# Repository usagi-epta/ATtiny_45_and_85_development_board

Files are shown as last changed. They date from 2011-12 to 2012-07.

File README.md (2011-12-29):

ATtiny 45 and 85 Development Board
==================================
Copyright 2011 Design Tech Industries (DTI)

DTI email: <jameskun89@rocketmail.com>

The **ATtiny 45 and 85 Development Board** is a development board for the ATtiny 45 and 85 microcontroller.

Features:

 * All µC pins broken out
 * Power LED
 * Reset switch
 * ISP headers 
 * Open Source; OSHW compliant
 * Design files freely available

In this repository you will find the gerber files for BatchPCB (http://batchpcb.com) and DorkbotPDX (http://dorkbotpdx.org/wiki/pcb_order),
along with project (.pro), board (.brd) and schematic (.sch) files for the board in the 'EAGLE and 'KiCad' folders.

You can also find this design on BatchPCB ready to add to your cart: http://batchpcb.com/index.php/Products/73630

**This board will be under continual change and versions may not work the way they are supposed to. You have been warned**

INSTALLATION
------------
**EAGLE**
The design is saved as an EAGLE project. EAGLE PCB design software is available from www.cadsoftusa.com 
free for non-commercial use and can be installed on Windows and Mac, with Linux support through WINE. 
To use this project download it and place the directory containing these files into the "eagle" directory 
on your computer. Then open EAGLE and navigate to Projects -> eagle -> ATtiny_45_and_85_development_board.

**KiCad**
KiCad EDA Suite is an Open Source alternative to EAGLE. It is available on Windows and Linux and can be installed 
on Mac. It is available from http://kicad.sourceforge.net and works in a similar way to EAGLE. You will find project 
files for KiCad in the aptly named folder in this repository. To use this project download it and place the directory 
containing these files into a folder of your choice. Then open KiCad and navigate to File -> Open -> 
'FOLDER_OF_YOUR_CHOICE' -> ATtiny_45_and_85_development_board.pro

BILL OF MATERIALS
-----------------

 * 1 x ATtiny 45/85 µC (http://littlebirdelectronics.com/products/avr-8-pin-20mhz-8k-4ad-attiny85)
 * 1 x 8-pin DIP socket (http://littlebirdelectronics.com/products/dip-sockets-solder-tail-8pin)
 * 2 x Female Header - 1x4-pin, Straight (http://littlebirdelectronics.com/products/0100-254-mm-female-header-1x4-pin-straight)
 * 1 x Break Away Header - Right Angle (http://littlebirdelectronics.com/products/break-away-headers-right-angle)
 * 1 x 5mm Green LED (http://littlebirdelectronics.com/products/basic-led-5mm-green)
 * 1 x 10uF Capacitor (http://littlebirdelectronics.com/products/electrolytic-decoupling-capacitors-10uf-25v)
 * 1 x 0.1uF Ceramic Capacitor (http://littlebirdelectronics.com/products/capacitor-ceramic-0-1uf)
 * 1 x 10K 1/4 resistor & 490K 1/4 resistor (can swap for 470K) (http://littlebirdelectronics.com/products/14-watt-carbon-film-resistors-300-pieces)
 * 1 x Mini Push Button Switch (http://littlebirdelectronics.com/products/mini-push-button-switch)

DISTRIBUTION
------------
The specific terms of distribution of this project are governed by the license referenced below.

LICENSE
-------
> This work is licensed under the Creative Commons Attribution-ShareAlike License.  
> 
> To view a copy of this license, visit:
> 
>   http://creativecommons.org/licenses/by-sa/3.0/  
>   http://creativecommons.org/licenses/by-sa/3.0/legalcode
> 
> or send a letter to
> 
>   Creative Commons  
>   171 Second Street, Suite 300  
>   San Francisco  
>   California, 94105  
>   USA

The "license" folder within this repository also contains copies of the
license(s) referenced above.

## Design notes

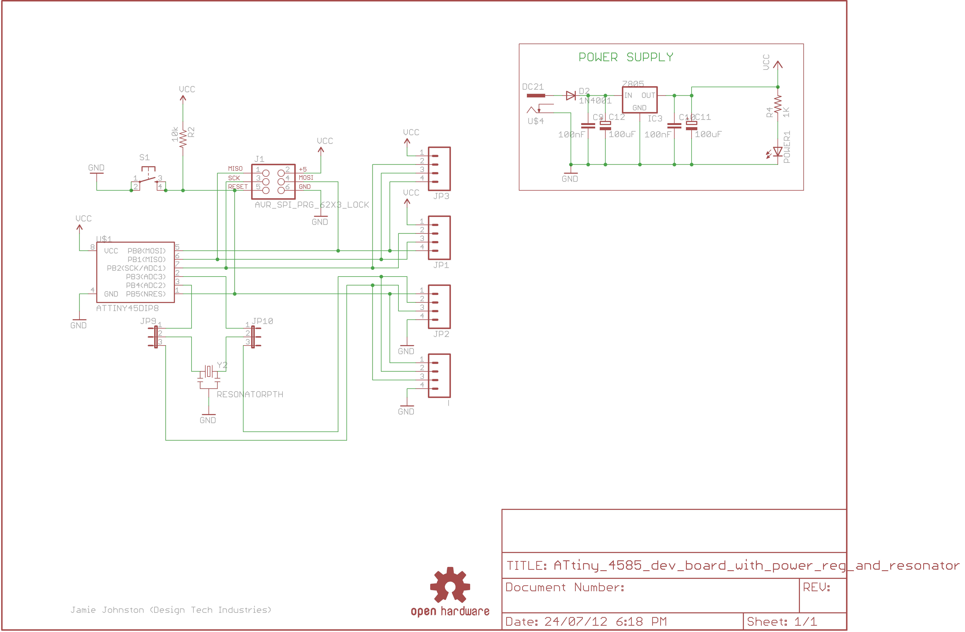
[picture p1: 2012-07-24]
docs/ATtiny_45_85_development_board_with_power_reg_and_resonator[schematic].png

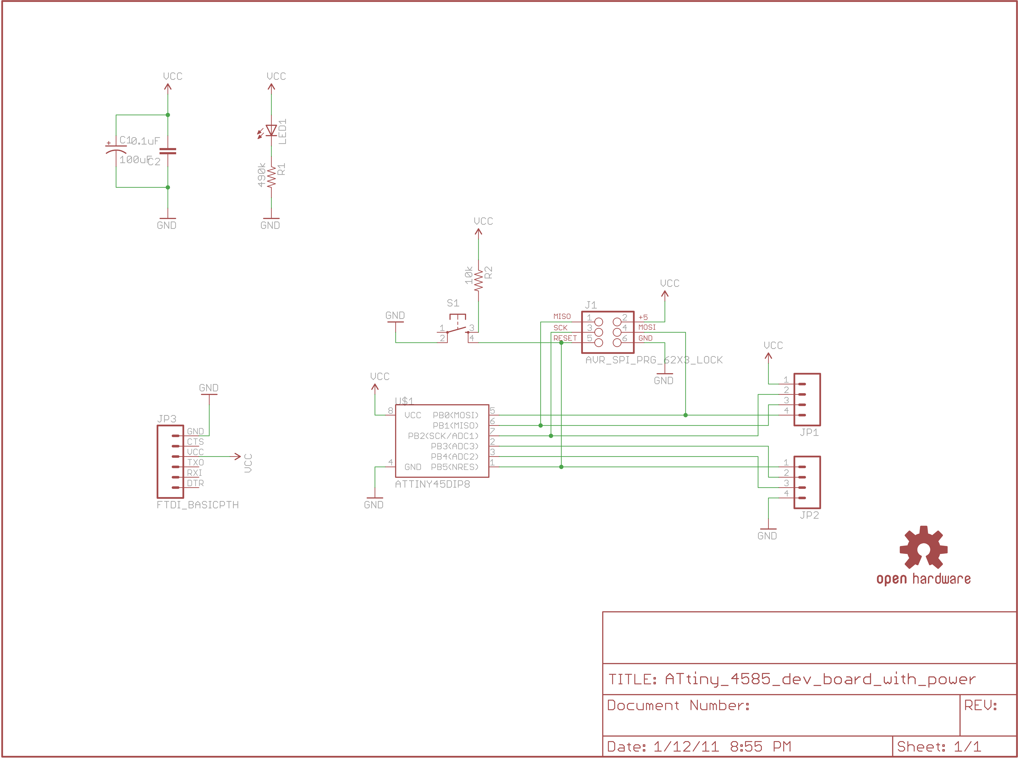
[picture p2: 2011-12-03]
docs/ATtiny_45_85_development_board_with_power[schematic].png

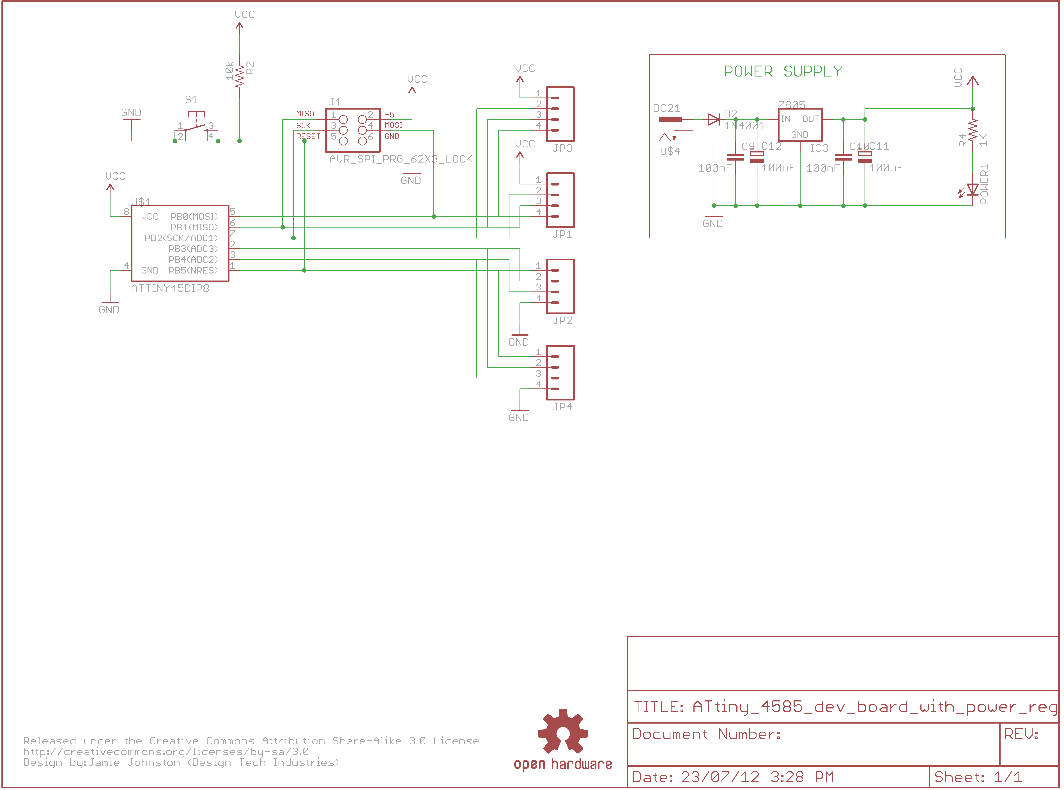
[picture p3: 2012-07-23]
docs/ATtiny_45_85_development_board_with_power_reg[schematic].png

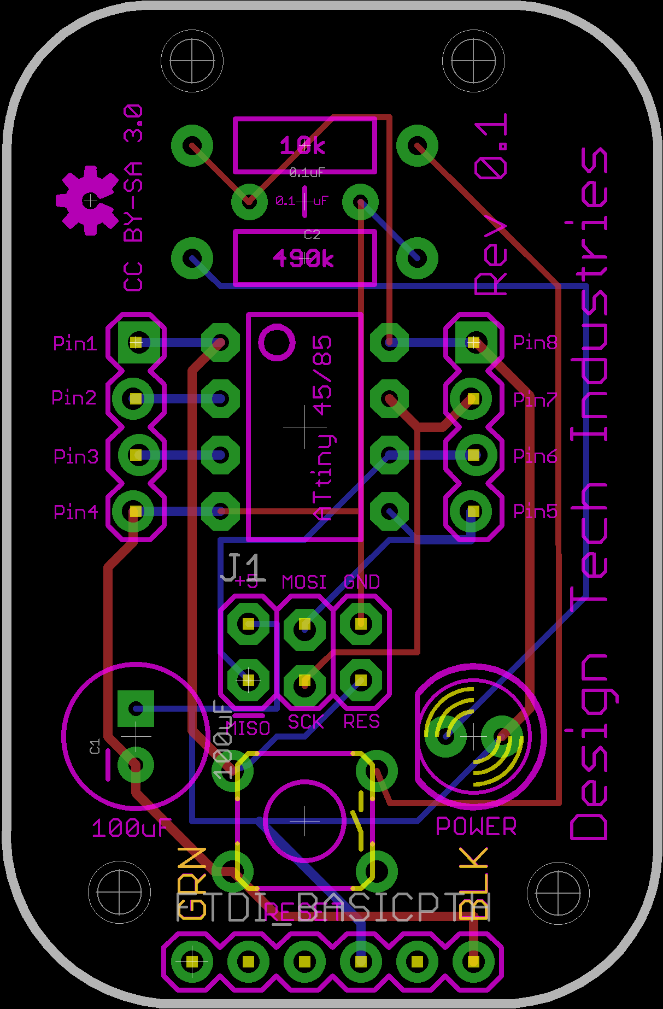
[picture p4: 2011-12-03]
docs/ATtiny_45_85_development_board_with_power.png

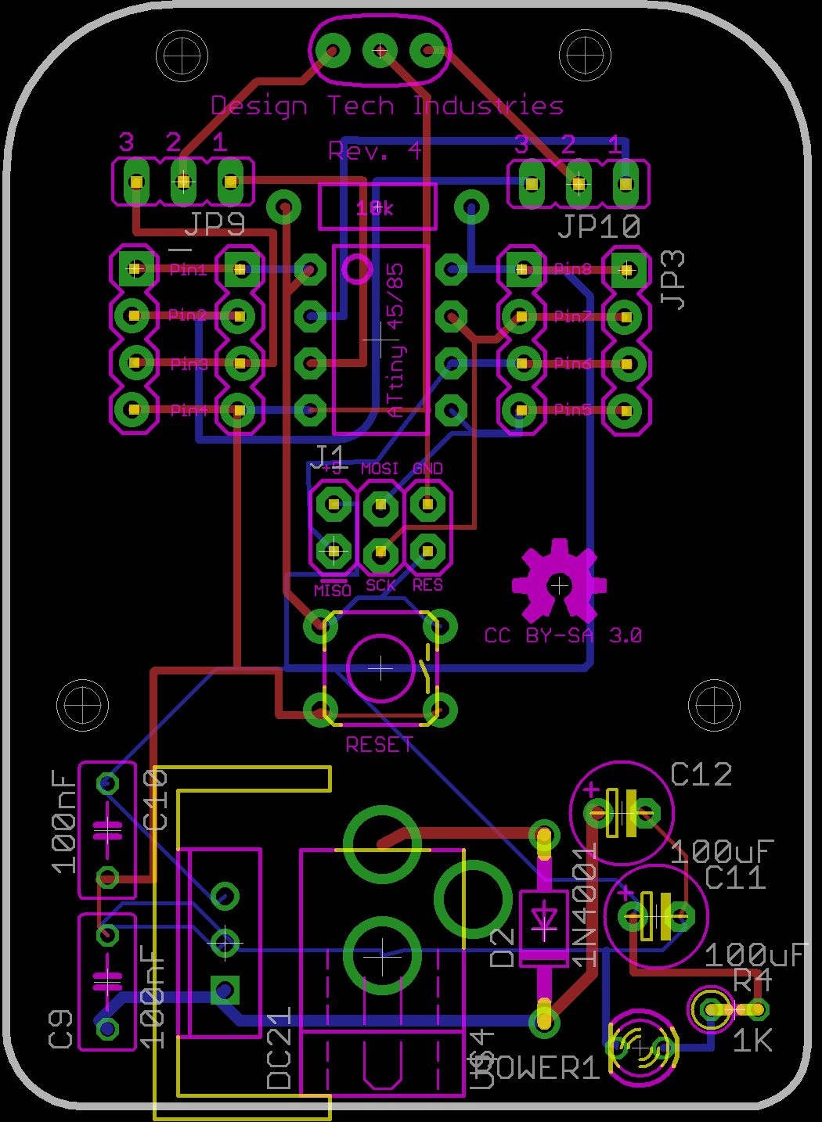
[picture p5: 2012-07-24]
docs/ATtiny_45_85_development_board_with_power_reg_and_resonator.png

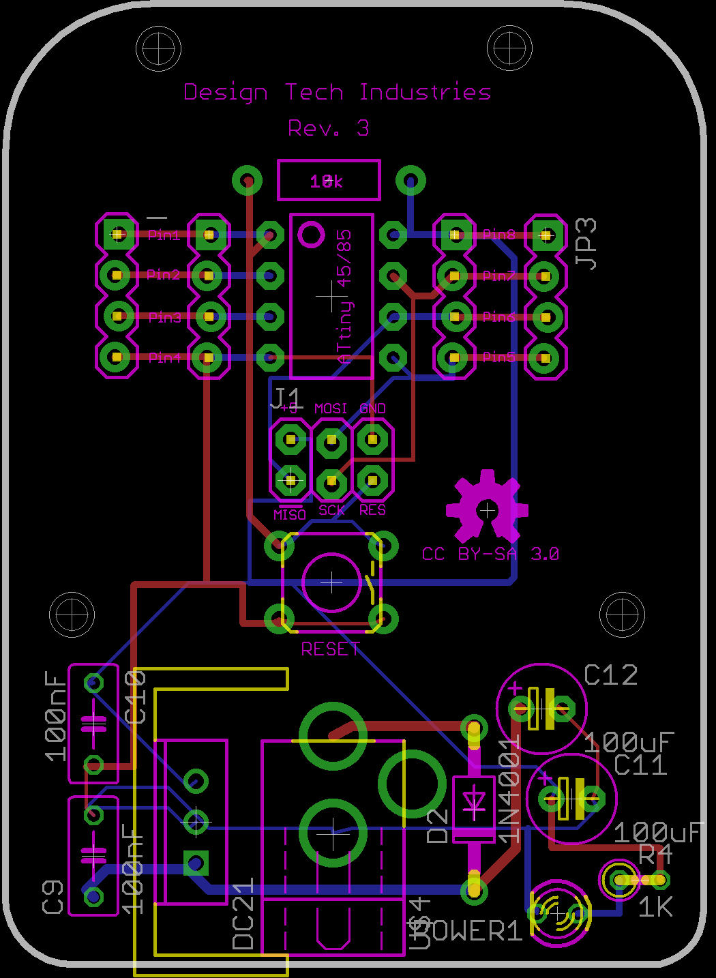
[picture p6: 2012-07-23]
docs/ATtiny_45_85_development_board_with_power_reg.png

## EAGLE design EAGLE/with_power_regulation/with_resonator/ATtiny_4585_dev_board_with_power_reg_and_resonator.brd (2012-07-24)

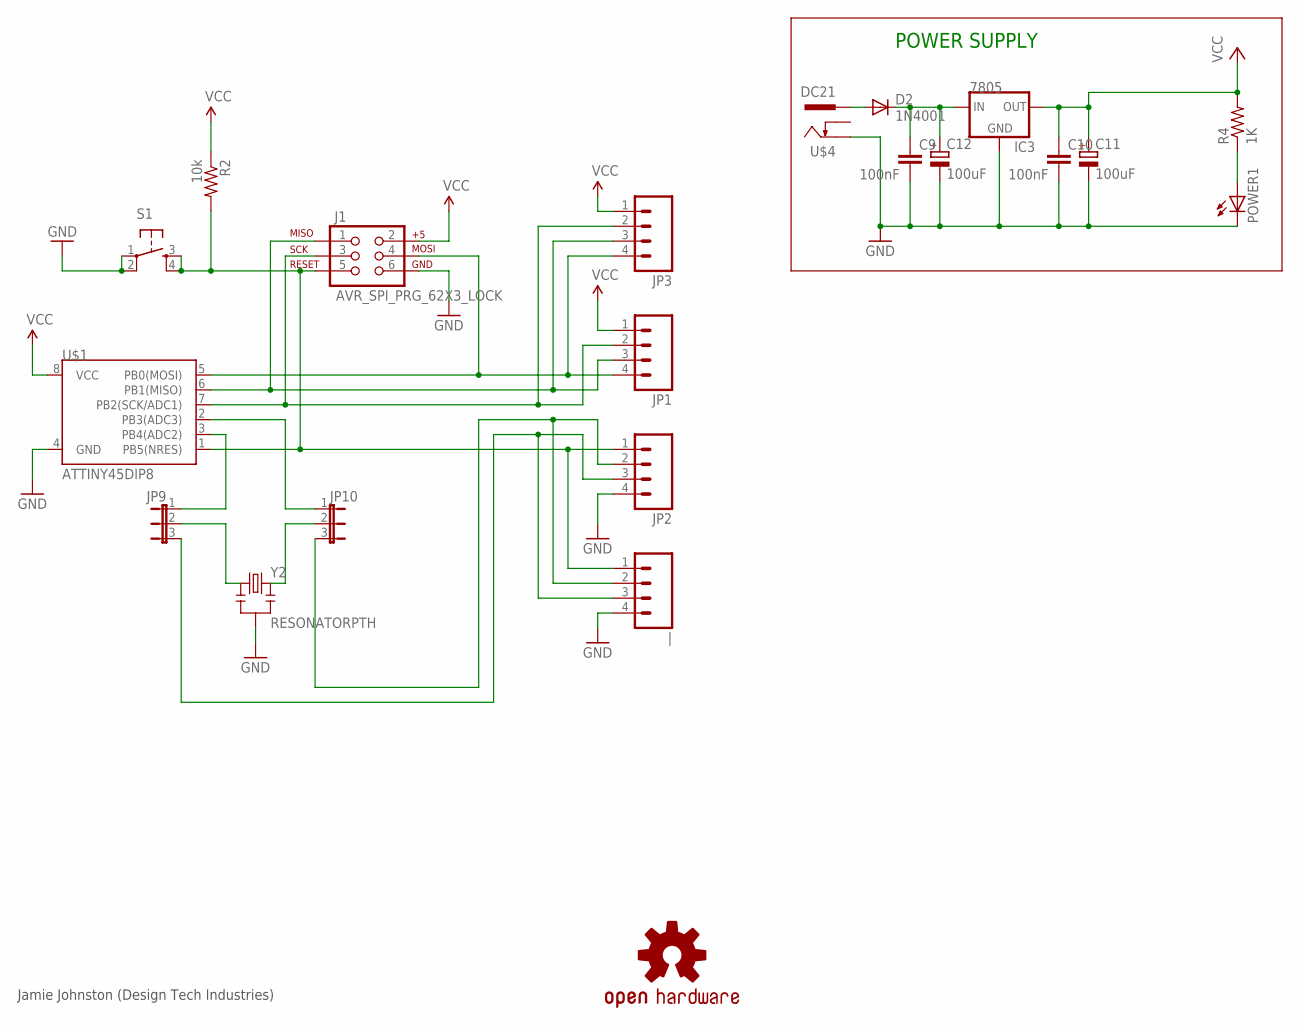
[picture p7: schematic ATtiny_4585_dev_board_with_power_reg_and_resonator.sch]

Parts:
C9, C10: 100nF; C050-030X075
C11, C12: 100uF; E2,5-6
D2: 1N4001; DO41-10
IC3: 7805; TO220-IGO
J1: AVR_SPI_PRG_62X3_LOCK; 2X3_LOCK
JP1, JP2, JP3: M04LOCK; 1X04_LOCK
JP9, JP10: JP2E; JP2
POWER1: LED3MM
R2: 10k; AXIAL-0.4
R4: 1K; 0207/2V
S1: TAC_SWITCHPTH; TACTILE-PTH
U$1: ATTINY45DIP8; DIP08
U$3: OSHW-LOGOM; OSHW-LOGO-M
U$4: DC21; DCSKT
Y2: RESONATORPTH; RESONATOR-PTH
|: M04LOCK; 1X04_LOCK

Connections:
GND: C9.2, C10.2, C11.-, C12.-, IC3.GND, J1.6, JP2.4, POWER1.K (C), S1.1, S1.2, U$1.4 (GND), U$4.2, Y2.2, |.4
unnamed: JP9.1, U$1.3 (PB4(ADC2))
unnamed: J1.4, JP1.4, JP3.4, U$1.5 (PB0(MOSI))
unnamed: J1.5, JP2.1, R2.P$2 (2), S1.3, S1.4, U$1.1 (PB5(NRES)), |.1
unnamed: JP10.1, U$1.2 (PB3(ADC3))
unnamed: J1.1, JP1.3, JP3.3, U$1.6 (PB1(MISO))
unnamed: J1.3, JP1.2, JP3.2, U$1.7 (PB2(SCK/ADC1))
unnamed: JP2.2, JP10.3, |.2
unnamed: JP2.3, JP9.3, |.3
unnamed: POWER1.A, R4.1
unnamed: JP9.2, Y2.1
unnamed: JP10.2, Y2.3
VCC: C10.1, C11.+, IC3.OUT, J1.2, JP1.1, JP3.1, R2.P$1 (1), R4.2, U$1.8 (VCC)
VIN: D2.A, U$4.1
VIN_SAFE: C9.1, C12.+, D2.C, IC3.IN

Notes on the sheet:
POWER SUPPLY
Jamie Johnston (Design Tech Industries)

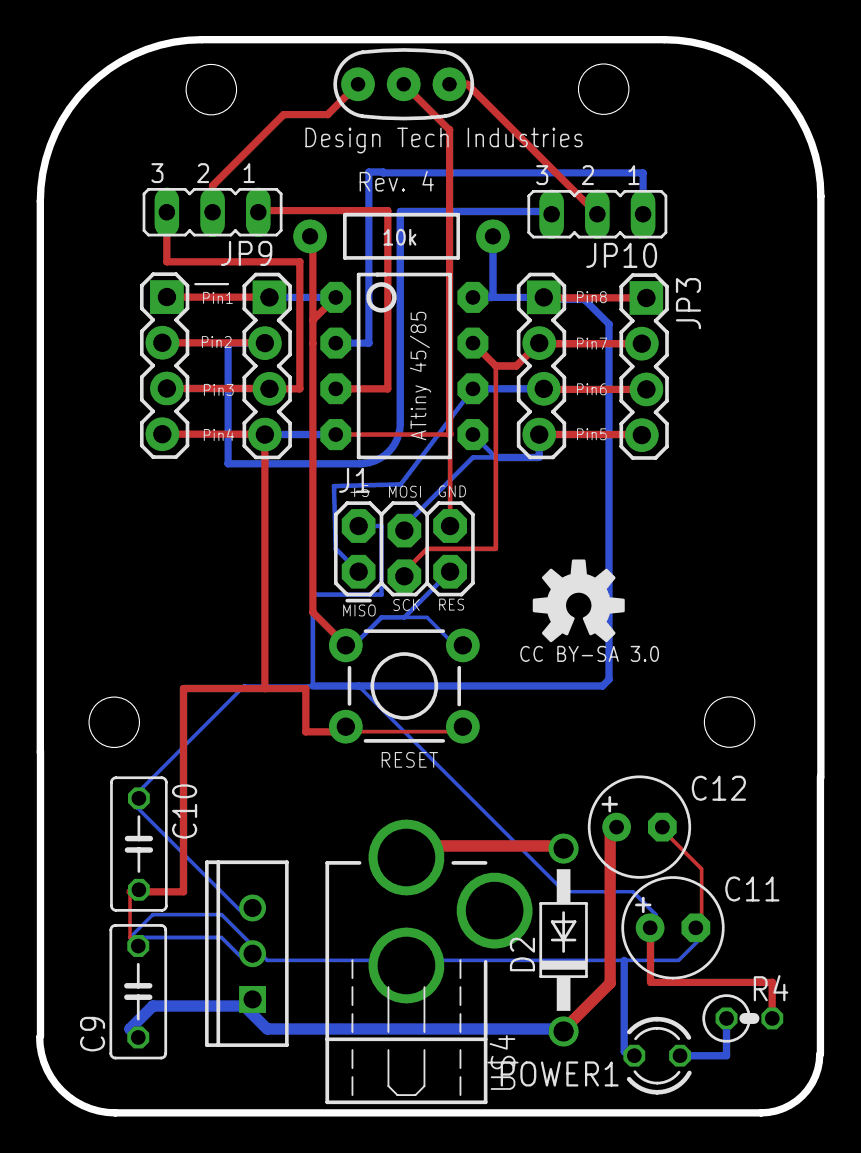
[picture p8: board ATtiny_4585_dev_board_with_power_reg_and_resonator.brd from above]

Board: 2 copper layers, 43.4 x 59.6 mm, 21 parts (0 on the bottom side), 15 nets.

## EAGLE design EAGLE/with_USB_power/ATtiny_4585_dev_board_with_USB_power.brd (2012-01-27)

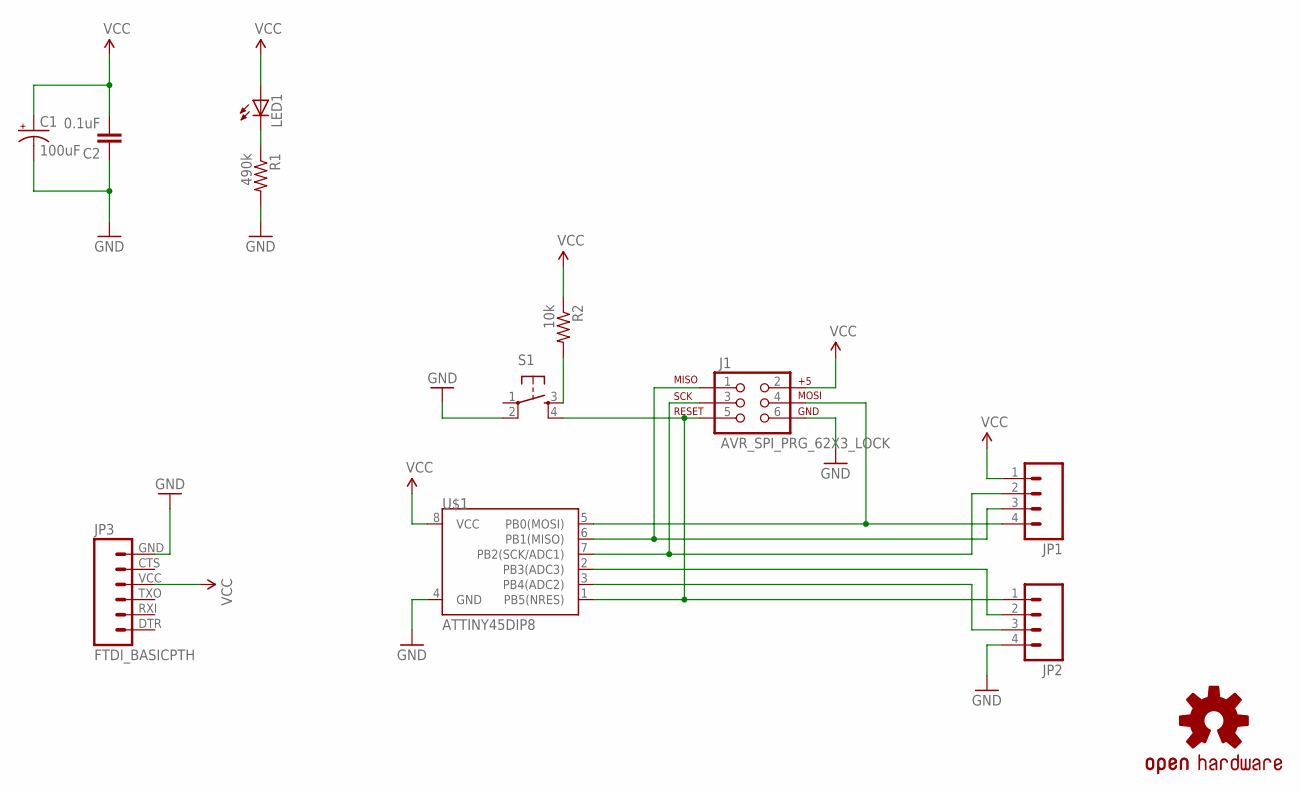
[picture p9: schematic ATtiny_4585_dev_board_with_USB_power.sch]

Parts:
C1: 100uF; CPOL-RADIAL-100UF-25V
C2: 0.1uF; CAP-PTH-5MM
J1: AVR_SPI_PRG_62X3_LOCK; 2X3_LOCK
JP1, JP2: M04LOCK; 1X04_LOCK
JP3: FTDI_BASICPTH; FTDI_BASIC
LED1: LED5MM
R1: 490k; AXIAL-0.4
R2: 10k; AXIAL-0.4
S1: TAC_SWITCHPTH; TACTILE-PTH
U$1: ATTINY45DIP8; DIP08
U$2: OSHW-LOGOS; OSHW-LOGO-S

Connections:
GND: C1.2 (-), C2.1, J1.6, JP2.4, JP3.GND (6), R1.P$2 (2), S1.2, U$1.4 (GND)
unnamed: LED1.K (C), R1.P$1 (1)
unnamed: J1.4, JP1.4, U$1.5 (PB0(MOSI))
unnamed: J1.5, JP2.1, S1.4, U$1.1 (PB5(NRES))
unnamed: J1.1, JP1.3, U$1.6 (PB1(MISO))
unnamed: J1.3, JP1.2, U$1.7 (PB2(SCK/ADC1))
unnamed: R2.P$2 (2), S1.3
unnamed: JP2.2, U$1.2 (PB3(ADC3))
unnamed: JP2.3, U$1.3 (PB4(ADC2))
VCC: C1.1 (+), C2.2, J1.2, JP1.1, JP3.VCC (4), LED1.A, R2.P$1 (1), U$1.8 (VCC)

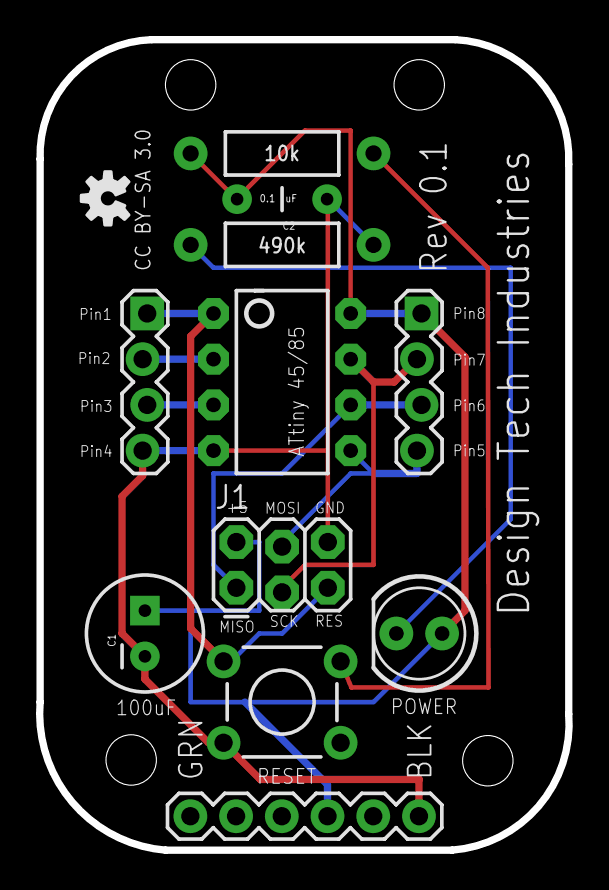
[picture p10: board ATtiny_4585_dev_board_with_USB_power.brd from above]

Board: 2 copper layers, 29.4 x 45.0 mm, 12 parts (0 on the bottom side), 10 nets.

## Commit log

2011-12-01 Initial commit of files.
    [ATtiny_45_85_development_board.brd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]
2011-12-01 Commit of newly created files, including design with power supply.
    [ATtiny_45_85_development_board.brd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]
2011-12-03 Commit of new files, including images of the board.
    [ATtiny_4585_dev_board_with_power.brd, ATtiny_4585_dev_board_with_power.sch]
2011-12-13 Upgraded to EAGLE 6 and resaved files in new XML format.
    [ATtiny_4585_dev_board_with_power.brd, ATtiny_4585_dev_board_with_power.sch, ATtiny_45_85_development_board.brd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]
2011-12-29 Added a Bill of Materials. Changes will be made once prototypes are made.
2012-01-27 Update to EAGLE 6.1.0
    [ATtiny_4585_dev_board_with_power.brd, ATtiny_4585_dev_board_with_power.sch]
2012-07-23 Added 5v power regulation and power jack. Included extra headers, breaking out the pins to the ATtiny45/85 chip to the bottom of board to allow unused pins to be used while 'shield' is in use.
    [ATtiny_4585_dev_board_with_power_reg.brd, ATtiny_4585_dev_board_with_power_reg.sch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]
2012-07-23 General folder clean up.
    [ATtiny_4585_dev_board_with_USB_power.brd, ATtiny_4585_dev_board_with_USB_power.sch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]
2012-07-23 Update of design files. Minor changes to thermocouple solder pads. New board images in 'docs' folder.
    [ATtiny_4585_dev_board_with_power_reg.brd, ATtiny_4585_dev_board_with_power_reg.sch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]
2012-07-24 Commit of revision 4 of board. This version now includes a resonator and selector jumpers, so as to allow you to choose if the resonator is needed or whether the pins are needed for something else.
    [ATtiny_4585_dev_board_with_power_reg_and_resonator.brd, ATtiny_4585_dev_board_with_power_reg_and_resonator.sch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]

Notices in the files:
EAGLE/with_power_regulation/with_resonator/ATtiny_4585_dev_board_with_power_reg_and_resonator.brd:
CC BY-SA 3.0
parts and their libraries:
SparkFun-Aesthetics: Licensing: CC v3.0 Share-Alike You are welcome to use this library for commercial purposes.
